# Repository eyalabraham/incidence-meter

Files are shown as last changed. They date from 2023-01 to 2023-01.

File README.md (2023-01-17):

# Incidence meter for RC planes

This project implements an incidence meter to measure airfoil angles on RC planes. The project uses an AVR ATMega328p, a set of seven segment LED modules, and an I2C accelerometer module.  Use to measure absolute of aerodynamic surface and relative angle between them.  Project includes code for AVR, schematic and Gerber files for circuit board, and CAD files for 3D printing of mechanical parts. 

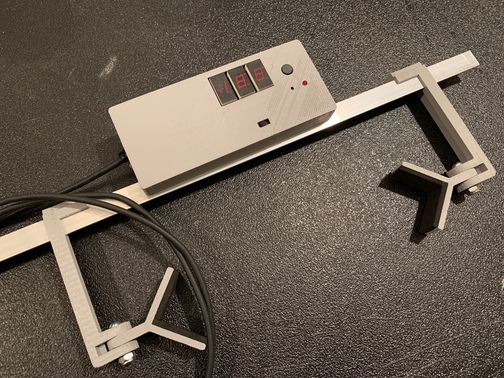
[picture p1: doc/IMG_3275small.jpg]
Incidence meter


## Using the meter

Assemble the circuit board and print the mechanical parts. Then assemble the meter as depicted here

<pic>

### Calibration 

Calibrate the meter before using for the first time and if using after long storage or changing mechanical parts. Calibration stores the zero angle error offset resulting from mechanical imperfections in the AVR EEPROM. 

1.	Stand the meter on a level surface, preferably one that was leveled with a separate leveling tool
2.	Turn on the meter.
3.	If the meter does not have stored calibration information then the calibration LED will blink continuously. You can still measure angles, but the measurements may not be accurate.
4.	Use a non-metal point tool to push the calibration button and check that the calibration LED turns on, or will stop blinking and stay on. 
5.	When ready, press the hold/zero button to store the calibration data. 
6.	The Calibration LED will turn off and the calibration LED should turn off indicating a valid calibration. 
7.	Calibration can be entered and repeated at any time as required. 

### Using the meter

The meter can be used to measure incidence angles on a plane’s aerodynamic surface (wing, stabilizer/elevator) or the relative angle between surfaces.

#### Surface angle

1.	Place the assembled air-frame on a leveled surface. Pre-level the surface with the meter (zero degree angle) or a different leveling tool. Level the surface in two directions at right angle to each other. 
2.	Clamp the meter to the surface. 
3.	Read the angle on the meter. 
4.	Note that this is the angle of incidence relative to the level surface; ground. 

#### Relative incidence angle

1.	Make sure ailerons and elevator are neutral. 
2.	Follow steps 1 through 3 above on the aircraft’s wing. 
3.	Press the Zero/Hold button 
4.	The display should read zero
5.	Move the meter and clamp to a different surface such as the horizontal stabilizer. 
6.	The reading on the meter now shows the relative incidence angle between horizontal stabilizer and wing. Positive or negative indicates a positive or negative incidence angle.
7.	Compare the measurement to the plans or manufacturer recommendations.

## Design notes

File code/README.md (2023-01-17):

# AVR ATMega328P incidence meter code

This project implements an incidence meter to measure airfoil angles on RC planes. The project uses an AVR ATMega328p, a set of seven segment LED modules, and an I2C accelerometer module.

KiCAD schematics capture and PCB design in ```schematics``` folder with [copy in PDF](../doc/incidence-meter.pdf) format.

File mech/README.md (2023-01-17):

# AVR ATMega328P incidence meter 3D mechanical model

This project implements an incidence meter to measure airfoil angles on RC planes. The project uses an AVR ATMega328p, a set of seven segment LED modules, and an I2C accelerometer module.

The parts are all 3D printer with PLA. Additional items include:
- "L" shaped aluminum angle rod 1/16" thin x 1/2" x 12" Home Depot SKU# 195627
- #6-32 x 1" screws and lock nuts
- #4 3/8" pan head sheet metal screws

[FreeCAD CAD file, STEP, and STL also on GrabCAD](https://grabcad.com/library/incidence-meter-1)

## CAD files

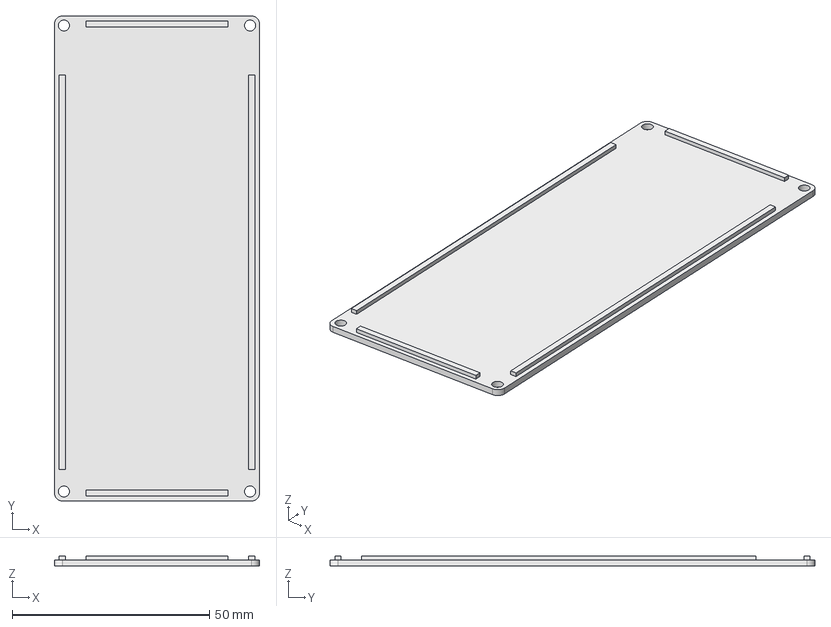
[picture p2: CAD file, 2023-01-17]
mech/incidence-meter-cover.step
52.0 x 123.0 x 2.60 mm

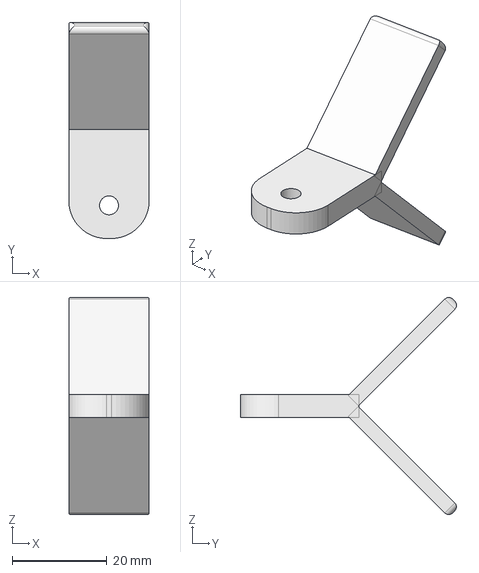
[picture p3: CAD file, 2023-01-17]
mech/incidence-meter-clamp.step
17.0 x 45.6 x 45.9 mm

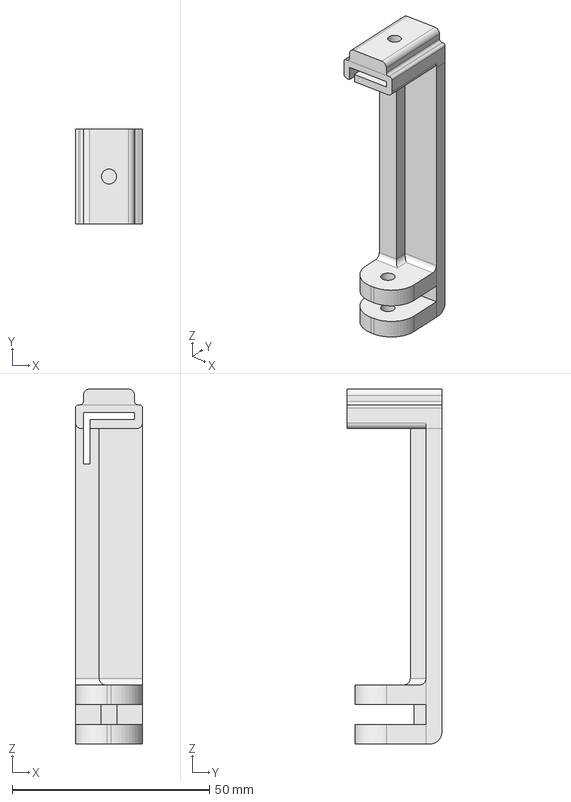
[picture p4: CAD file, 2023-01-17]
mech/incidence-meter-right-arm.step
17.0 x 24.0 x 90.0 mm

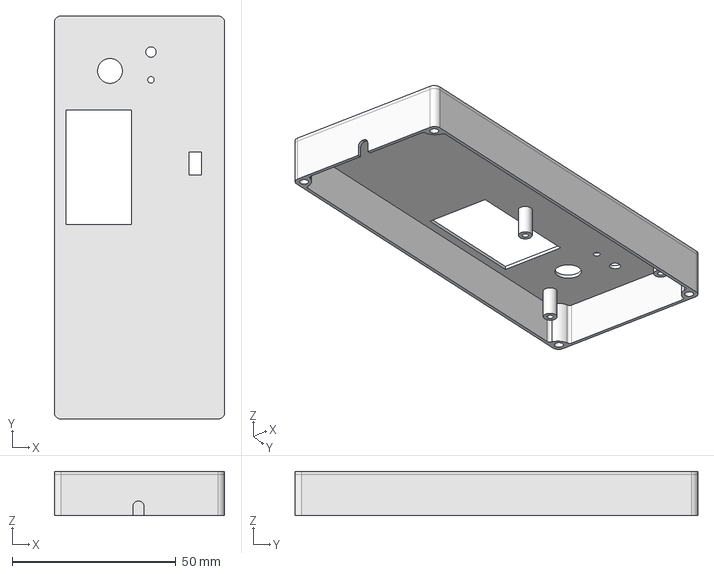
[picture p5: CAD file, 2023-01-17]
mech/incidence-meter-box.step
52.0 x 123.0 x 13.5 mm

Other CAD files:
mech/incidence-meter-left-arm.step
mech/incidence-meter-box.stl
mech/incidence-meter-clamp.stl
mech/incidence-meter-cover.stl
mech/incidence-meter-left-arm.stl
mech/incidence-meter-right-arm.stl

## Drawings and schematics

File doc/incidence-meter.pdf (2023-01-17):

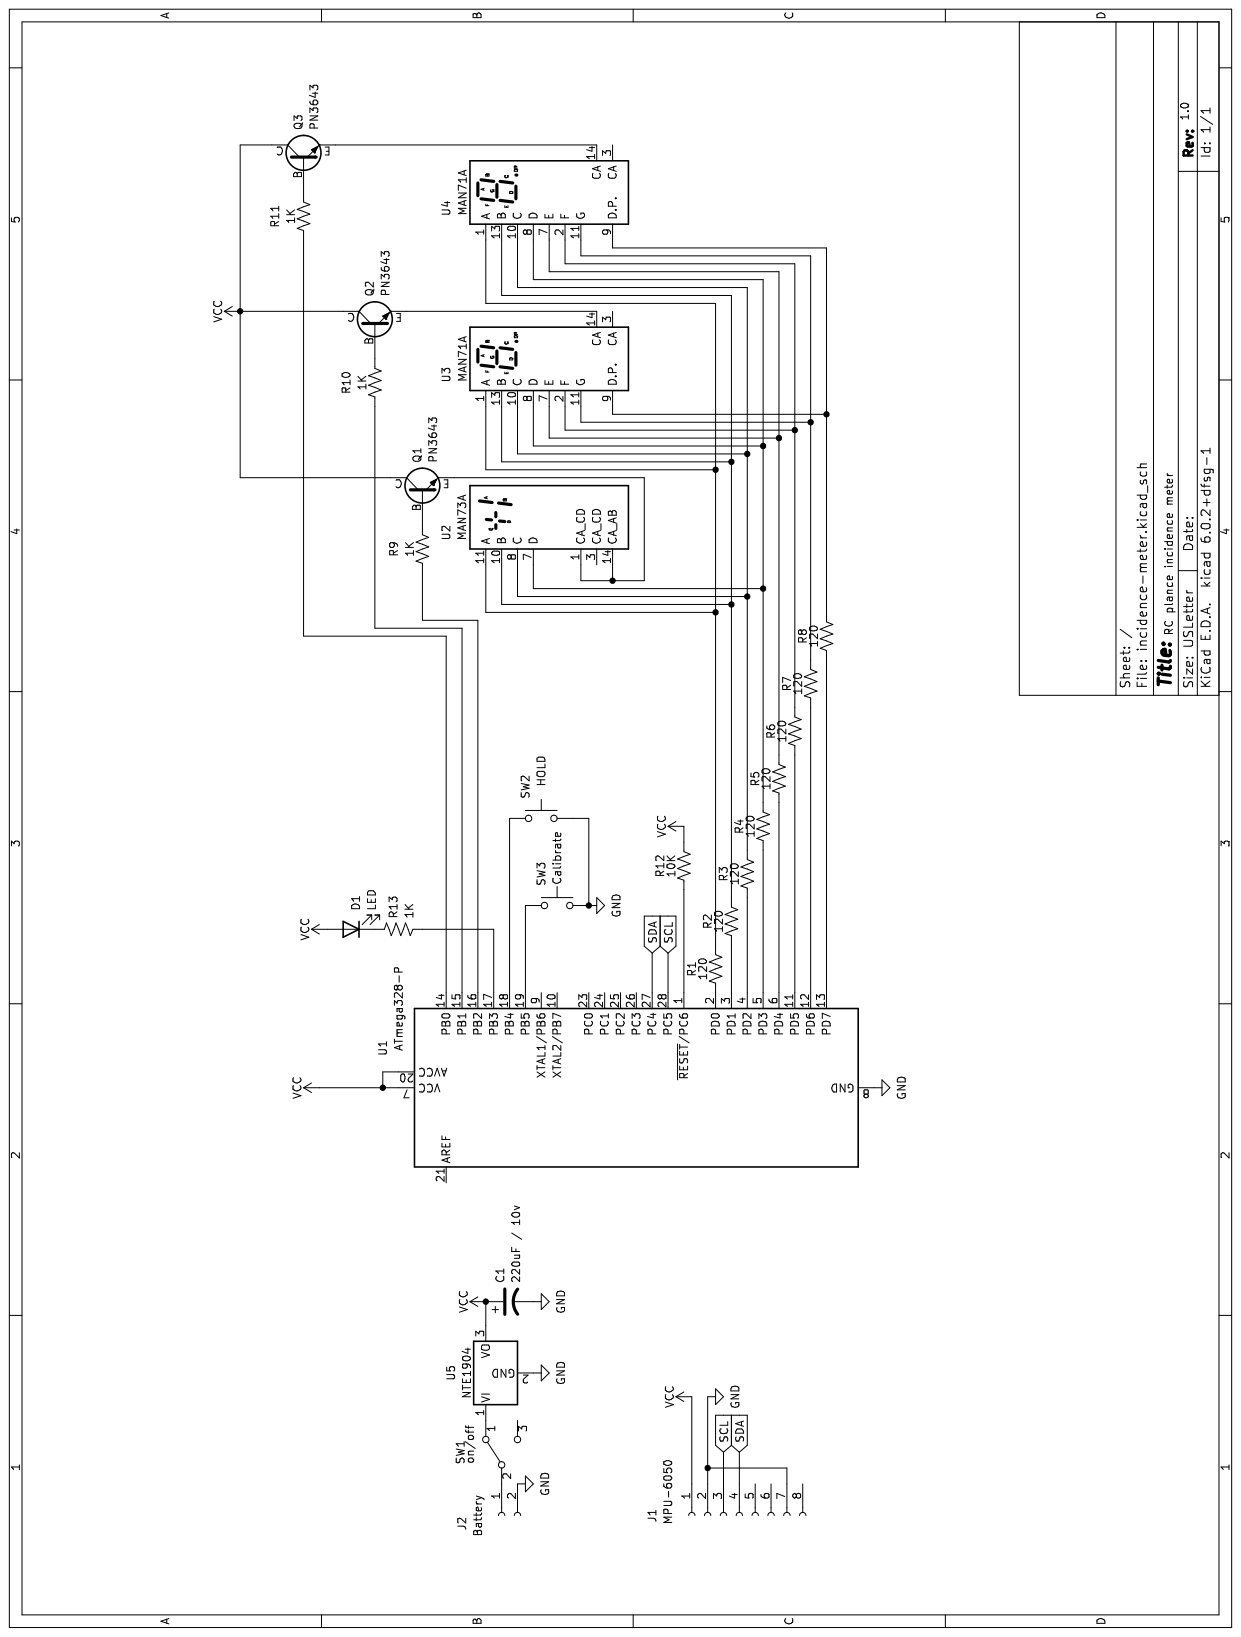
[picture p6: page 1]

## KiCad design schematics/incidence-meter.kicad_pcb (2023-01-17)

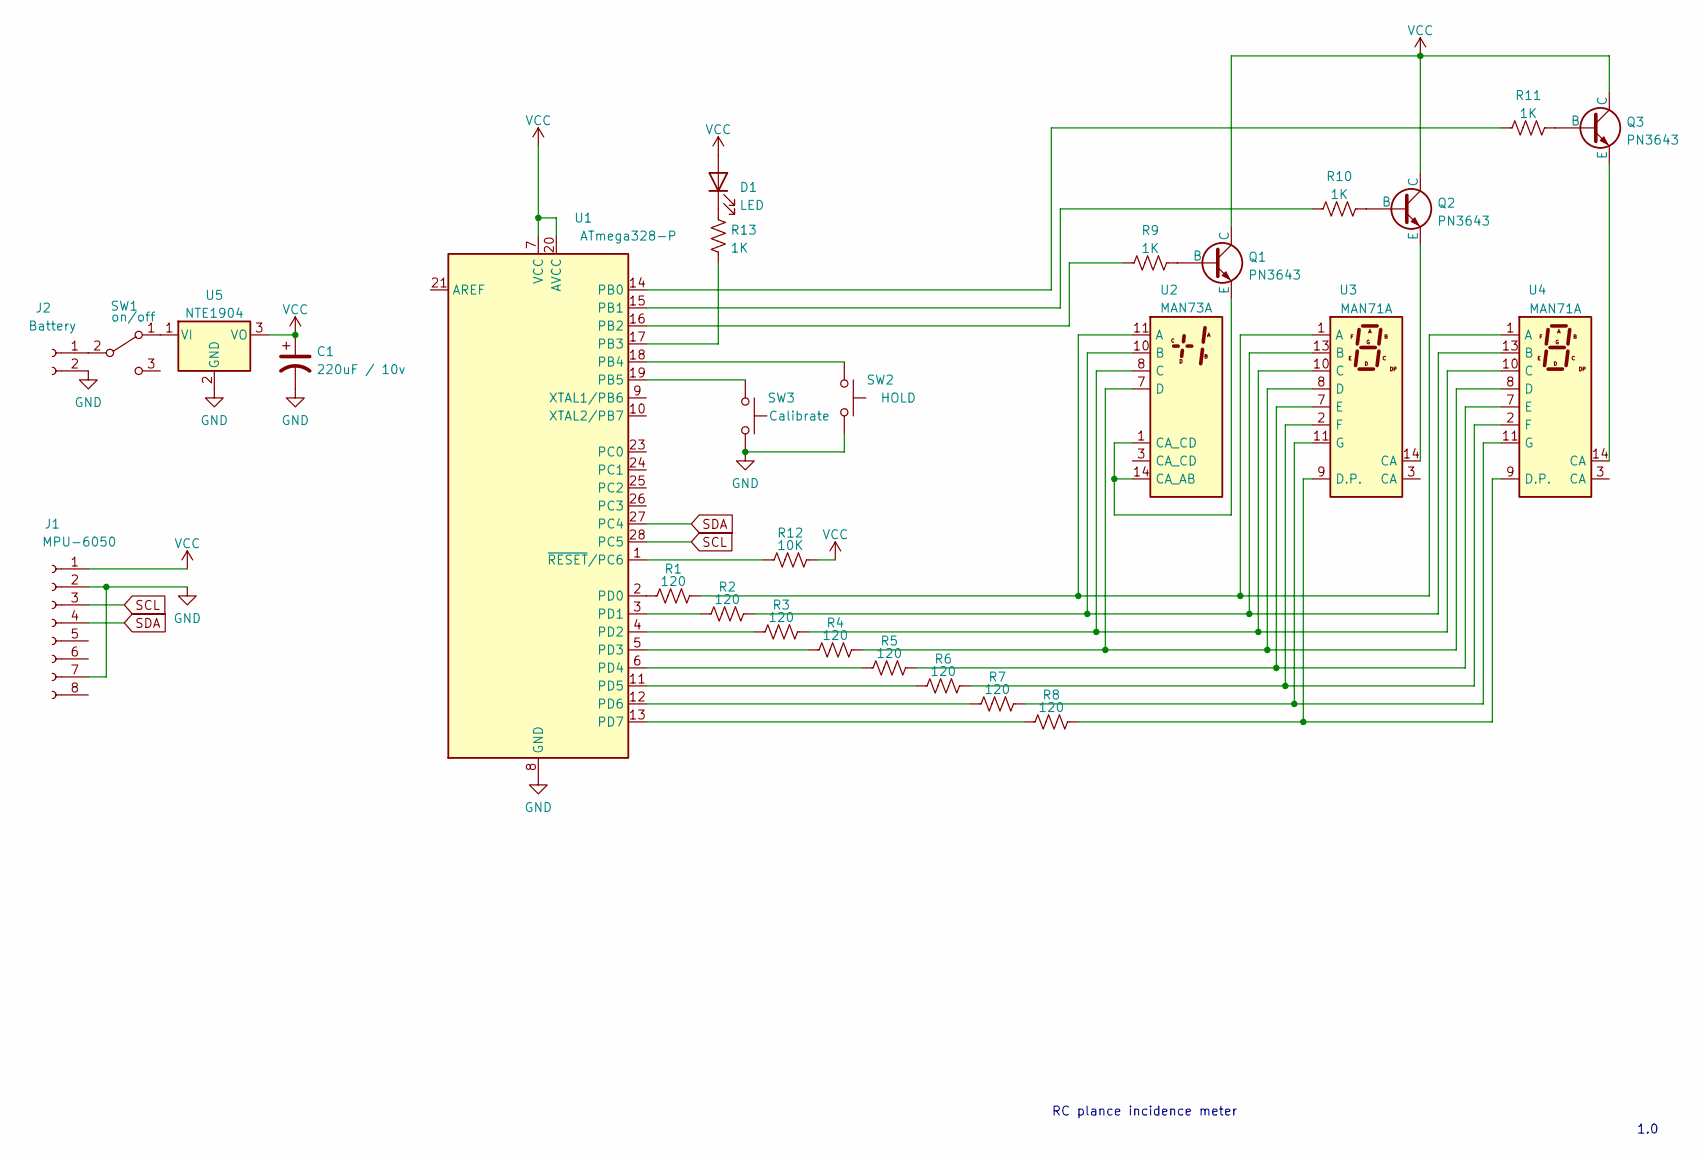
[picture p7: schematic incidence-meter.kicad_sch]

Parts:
C1: 220uF / 10v; CP_Radial_D6.3mm_P2.50mm
D1: LED; LED_D3.0mm
J1: MPU-6050; PinSocket_1x08_P2.54mm_Vertical
J2: Battery; PinHeader_1x02_P2.54mm_Vertical
Q1, Q2, Q3: PN3643; TO-92L_HandSolder
R1, R2, R3, R4, R5, R6, R7, R8: 120; R_Axial_DIN0207_L6.3mm_D2.5mm_P7.62mm_Horizontal
R9, R10, R11, R13: 1K; R_Axial_DIN0207_L6.3mm_D2.5mm_P7.62mm_Horizontal
R12: 10K; R_Axial_DIN0207_L6.3mm_D2.5mm_P7.62mm_Horizontal
SW1: on/off; SPDT_MINIATURE_SLIDE_SW_PHILMORE_30-9185
SW2: HOLD; SW_PUSH-12mm
SW3: Calibrate; SW_Tactile_Straight_KSA0Axx1LFTR
U1: ATmega328-P; DIP-28_W7.62mm
U2: MAN73A
U3, U4: MAN71A
U5: NTE1904; TO-220-3_Vertical

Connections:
GND: C1.2, J1.2, J1.7, J2.2, SW2.2, SW3.2, U1.8 (GND), U1.22 (GND), U5.2 (GND)
unnamed: D1.1 (K), R13.2
unnamed: J2.1, SW1.2 (B)
unnamed: Q1.1 (E), U2.1 (CA_CD), U2.14 (CA_AB)
unnamed: Q1.2 (B), R9.1
unnamed: Q2.1 (E), U3.14 (CA)
unnamed: Q2.2 (B), R10.1
unnamed: Q3.1 (E), U4.14 (CA)
unnamed: Q3.2 (B), R11.1
unnamed: R1.1, U2.11 (A), U3.1 (A), U4.1 (A)
unnamed: R1.2, U1.2 (PD0)
unnamed: R2.1, U2.10 (B), U3.13 (B), U4.13 (B)
unnamed: R2.2, U1.3 (PD1)
unnamed: R3.1, U2.8 (C), U3.10 (C), U4.10 (C)
unnamed: R3.2, U1.4 (PD2)
unnamed: R4.1, U2.7 (D), U3.8 (D), U4.8 (D)
unnamed: R4.2, U1.5 (PD3)
unnamed: R5.1, U3.7 (E), U4.7 (E)
unnamed: R5.2, U1.6 (PD4)
unnamed: R6.1, U3.2 (F), U4.2 (F)
unnamed: R6.2, U1.11 (PD5)
unnamed: R7.1, U3.11 (G), U4.11 (G)
unnamed: R7.2, U1.12 (PD6)
unnamed: R8.1, U3.9 (D.P.), U4.9 (D.P.)
unnamed: R8.2, U1.13 (PD7)
unnamed: R9.2, U1.16 (PB2)
unnamed: R10.2, U1.15 (PB1)
unnamed: R11.2, U1.14 (PB0)
unnamed: R12.2, U1.1 (~RESET/PC6)
unnamed: R13.1, U1.17 (PB3)
unnamed: SW1.1 (A), U5.1 (VI)
unnamed: SW2.1, U1.18 (PB4)
unnamed: SW3.1, U1.19 (PB5)
SCL: J1.3, U1.28 (PC5)
SDA: J1.4, U1.27 (PC4)
VCC: C1.1, D1.2 (A), J1.1, Q1.3 (C), Q2.3 (C), Q3.3 (C), R12.1, U1.7 (VCC), U1.20 (AVCC), U5.3 (VO)

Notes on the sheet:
1.0
RC plance incidence meter

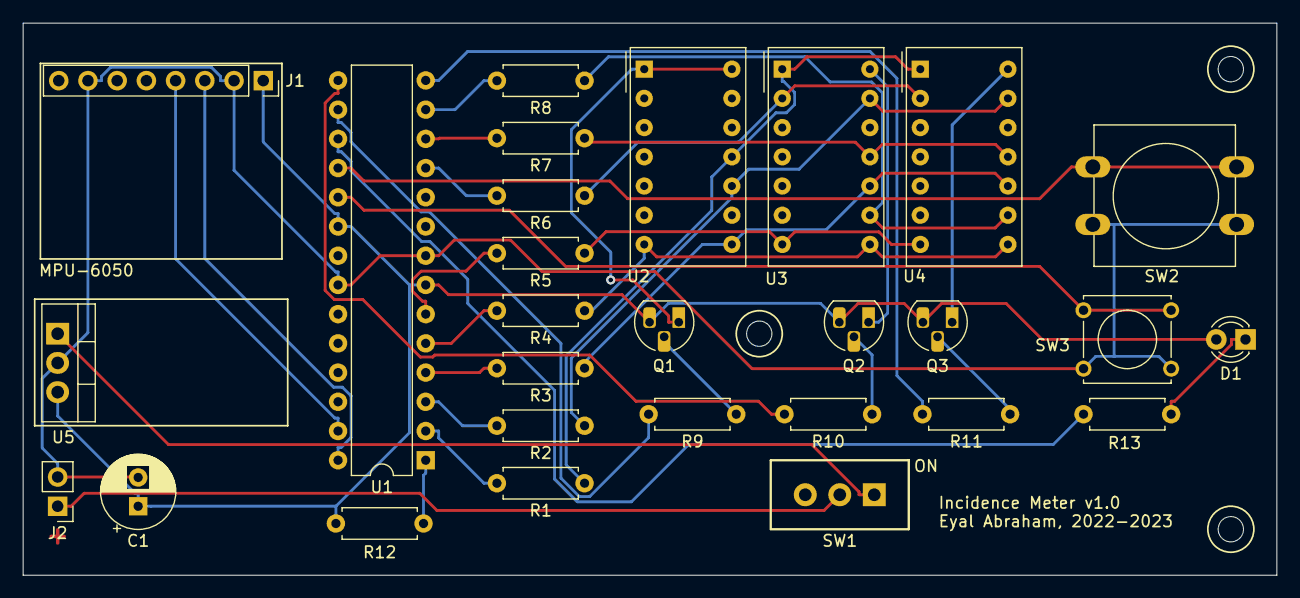
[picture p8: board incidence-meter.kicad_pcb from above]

Board: 2 copper layers, 109.0 x 48.0 mm, 28 parts (0 on the bottom side), 36 nets.

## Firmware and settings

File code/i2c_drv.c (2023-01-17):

/*****************************************************************************
* i2c_drv.c
*
*  Driver for AVT TWI (I2C) interface for
*  bus controller 'i2c_c_*' and peripheral 'i2c_p_*'.
*  This is driver can be use as interrupt driven.
*
*  Modified: December 2022, added time-out in controller blocking functions.
*  Created:  December 2014
*
*****************************************************************************/

#include    <stdint.h>
#include    <string.h>
#include    <avr/io.h>
#include    <avr/interrupt.h>
#include    <util/twi.h>
#include    <util/delay.h>

#include    "inc/i2c_drv.h"

/****************************************************************************
  TWI State codes
****************************************************************************/
// General TWI controller status codes
#define TWI_START                  0x08     // START has been transmitted
#define TWI_REP_START              0x10     // Repeated START has been transmitted
#define TWI_ARB_LOST               0x38     // Arbitration lost

// TWI controller Transmitter status codes
#define TWI_MTX_ADR_ACK            0x18     // SLA+W has been transmitted and ACK received
#define TWI_MTX_ADR_NACK           0x20     // SLA+W has been transmitted and NACK received
#define TWI_MTX_DATA_ACK           0x28     // Data byte has been transmitted and ACK received
#define TWI_MTX_DATA_NACK          0x30     // Data byte has been transmitted and NACK received

// TWI controller Receiver status codes
#define TWI_MRX_ADR_ACK            0x40     // SLA+R has been transmitted and ACK received
#define TWI_MRX_ADR_NACK           0x48     // SLA+R has been transmitted and NACK received
#define TWI_MRX_DATA_ACK           0x50     // Data byte has been received and ACK transmitted
#define TWI_MRX_DATA_NACK          0x58     // Data byte has been received and NACK transmitted

// TWI peripheral Transmitter status codes
#define TWI_STX_ADR_ACK            0xA8     // Own SLA+R has been received; ACK has been returned
#define TWI_STX_ADR_ACK_M_ARB_LOST 0xB0     // Arbitration lost in SLA+R/W as controller; own SLA+R has been received; ACK has been returned
#define TWI_STX_DATA_ACK           0xB8     // Data byte in TWDR has been transmitted; ACK has been received
#define TWI_STX_DATA_NACK          0xC0     // Data byte in TWDR has been transmitted; NOT ACK has been received
#define TWI_STX_DATA_ACK_LAST_BYTE 0xC8     // Last data byte in TWDR has been transmitted (TWEA = '0'); ACK has been received

// TWI peripheral Receiver status codes
#define TWI_SRX_ADR_ACK            0x60     // Own SLA+W has been received ACK has been returned
#define TWI_SRX_ADR_ACK_M_ARB_LOST 0x68     // Arbitration lost in SLA+R/W as controller; own SLA+W has been received; ACK has been returned
#define TWI_SRX_GEN_ACK            0x70     // General call address has been received; ACK has been returned
#define TWI_SRX_GEN_ACK_M_ARB_LOST 0x78     // Arbitration lost in SLA+R/W as controller; General call address has been received; ACK has been returned
#define TWI_SRX_ADR_DATA_ACK       0x80     // Previously addressed with own SLA+W; data has been received; ACK has been returned
#define TWI_SRX_ADR_DATA_NACK      0x88     // Previously addressed with own SLA+W; data has been received; NOT ACK has been returned
#define TWI_SRX_GEN_DATA_ACK       0x90     // Previously addressed with general call; data has been received; ACK has been returned
#define TWI_SRX_GEN_DATA_NACK      0x98     // Previously addressed with general call; data has been received; NOT ACK has been returned
#define TWI_SRX_STOP_RESTART       0xA0     // A STOP condition or repeated START condition has been received while still addressed as peripheral

// TWI Miscellaneous status codes
#define TWI_NO_STATE               0xF8     // No relevant state information available; TWINT = '0'
#define TWI_BUS_ERROR              0x00     // Bus error due to an illegal START or STOP condition

// TWCR bit set/reset macro
#define set_p_TWCR(sta,sto,intr,ea) (((intr)<<TWINT)|   \
                                     ((ea)<<TWEA)|      \
                                     ((sta)<<TWSTA)|    \
                                     ((sto)<<TWSTO)|    \
                                     (0<<TWWC)|         \
                                     (1<<TWEN)|         \
                                     (1<<TWIE))

#define set_c_TWCR(sta,sto,intr,ea) (((intr)<<TWINT)|   \
                                     ((ea)<<TWEA)|      \
                                     ((sta)<<TWSTA)|    \
                                     ((sto)<<TWSTO)|    \
                                     (0<<TWWC)|         \
                                     (1<<TWEN)|         \
                                     (0<<TWIE))

#define TIME_OUT_INTERVAL           10      // Time out interval in mSec
#define TIME_OUT                    10      // In increments of TIME_OUT_INTERVAL, positive and 0
                                            // Time out = TIME_OUT x TIME_OUT_INTERVAL

/****************************************************************************
  Globals
****************************************************************************/

// TWI peripheral globals
static  volatile uint8_t i2c_genCallActive = 0;
static  volatile uint8_t i2c_rx_busy       = 0;   // busy receiving
static  volatile uint8_t i2c_tx_busy       = 0;   // busy transmitting
static           uint8_t txDataCount       = 0;   // bytes to transmit
static           uint8_t bytesToMove;

// TWI controller globals
static           uint8_t peripheralAddress;
static           uint8_t data[2];

// Common mode globals
static  volatile uint8_t rxIndex           = 0;   // index to data in rxBuffers
static  volatile uint8_t txIndex           = 0;   // index to data in txBuffers
static           uint8_t rxBuffer[TWI_BUFF_LEN];  // receive data buffer
static           uint8_t txBuffer[TWI_BUFF_LEN];  // transmit data buffer

/* ---------------------------------------------------------------------------
 * i2c_c_initialize()
 *
 *  Setup SCL clock rate for controller mode
 *
 */
void i2c_c_initialize(void)
{
    TWBR = 2;   // rate divisor to yield 400KHz SCL @ 8MHz CPU clock
    TWSR = 0;
}
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

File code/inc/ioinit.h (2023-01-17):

/*****************************************************************************
* ioinit.h
*
* IO initialization definitions
*
* Created: December 2022
*
*****************************************************************************/

#ifndef __IOINIT_H__
#define __IOINIT_H__

/*
 *
 * Port B bit assignment
 *
 * b7 b6 b5 b4 b3 b2 b1 b0
 * |  |  |  |  |  |  |  |
 * |  |  |  |  |  |  |  +--- 'o' Right digit   [8.]
 * |  |  |  |  |  |  +------ 'o' Middile digit [8.]
 * |  |  |  |  |  +--------- 'o' Left digit    [+1]
 * |  |  |  |  +------------ 'o' Calibration indicator LED
 * |  |  |  +--------------- 'i' Hold/zero measurement push-button
 * |  |  +------------------ 'i' Calibrate push-button
 * |  +--------------------- 'i'
 * +------------------------ 'i'
 *
 * Port C bit assignment
 *
 *    b6 b5 b4 b3 b2 b1 b0
 *    |  |  |  |  |  |  |
 *    |  |  |  |  |  |  +--- 'i'
 *    |  |  |  |  |  +------ 'i'
 *    |  |  |  |  +--------- 'i'
 *    |  |  |  +------------ 'i'
 *    |  |  +--------------- 'i' SDA
 *    |  +------------------ 'i' SCL
 *    +--------------------- 'i' Reset input
 *
 * Port D bit assignment
 *
 * b7 b6 b5 b4 b3 b2 b1 b0
 * |  |  |  |  |  |  |  |
 * |  |  |  |  |  |  |  +--- 'o' Segment 'a'
 * |  |  |  |  |  |  +------ 'o' Segment 'b'
 * |  |  |  |  |  +--------- 'o' Segment 'c'
 * |  |  |  |  +------------ 'o' Segment 'd'
 * |  |  |  +--------------- 'o' Segment 'e'
 * |  |  +------------------ 'o' Segment 'f'
 * |  +--------------------- 'o' Segment 'g'
 * +------------------------ 'o' Segment 'dp'
 *
 */
 
/****************************************************************************
  Definitions
****************************************************************************/
/* IO port B initialization
 */
#define     PB_DDR_INIT     0b00001111  // Port data direction
#define     PB_PUP_INIT     0b00110000  // Port input pin pull-up
#define     PB_INIT         0b00001000  // Port initial values

/* IO port C initialization
 */
#define     PC_DDR_INIT     0b00000000  // Port data direction
#define     PC_PUP_INIT     0b00000000  // Port input pin pull-up
#define     PC_INIT         0b00000000  // Port initial values

/* IO port D initialization
 */
#define     PD_DDR_INIT     0b11111111  // Port data direction
#define     PD_PUP_INIT     0b00000000  // Port input pin pull-up
#define     PD_INIT         0b11111111  // Port initial values

/* Timer0 initialization
 * With 8MHz internal clock: 150Hz / 6.7 [mSec]
 */
#define     TCCR0A_INIT     0b00000010  // Normal mode, CTC to OCRA
#define     TCCR0B_INIT     0b00000101  // Mode-0 timer, Clk/1024
#define     OCR0A_INIT      52          // OCR0A value for ~150Hz interrupt
#define     TIMSK_INIT      0b00000010  // Enable Timer0 OCRA match interrupt

#endif /* __IOINIT_H__ */
